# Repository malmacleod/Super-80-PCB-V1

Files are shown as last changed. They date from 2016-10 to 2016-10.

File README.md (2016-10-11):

# Super-80 PCB (V1)

This repository stores the KiCad files (schematic and PCB) for the work-in-progress task of creating a reproduction of the Super 80 Computer.

The schematic is fully drawn.

As at 11-OCT-2016, the PCB is about 50% completed.

This will be as close a copy as possible to the original design.  Once this board has been completed, a slightly modified version will then be created, to overcome problems associated with components that are no longer available (such as the keyswitches).

STATUS:

11-OCT-2016: Added bottom layer traces in the vicinity of the 3 24-pin ICs U26, U33 and U42.

10-OCT-2016: Initial upload of KiCad files to Github.

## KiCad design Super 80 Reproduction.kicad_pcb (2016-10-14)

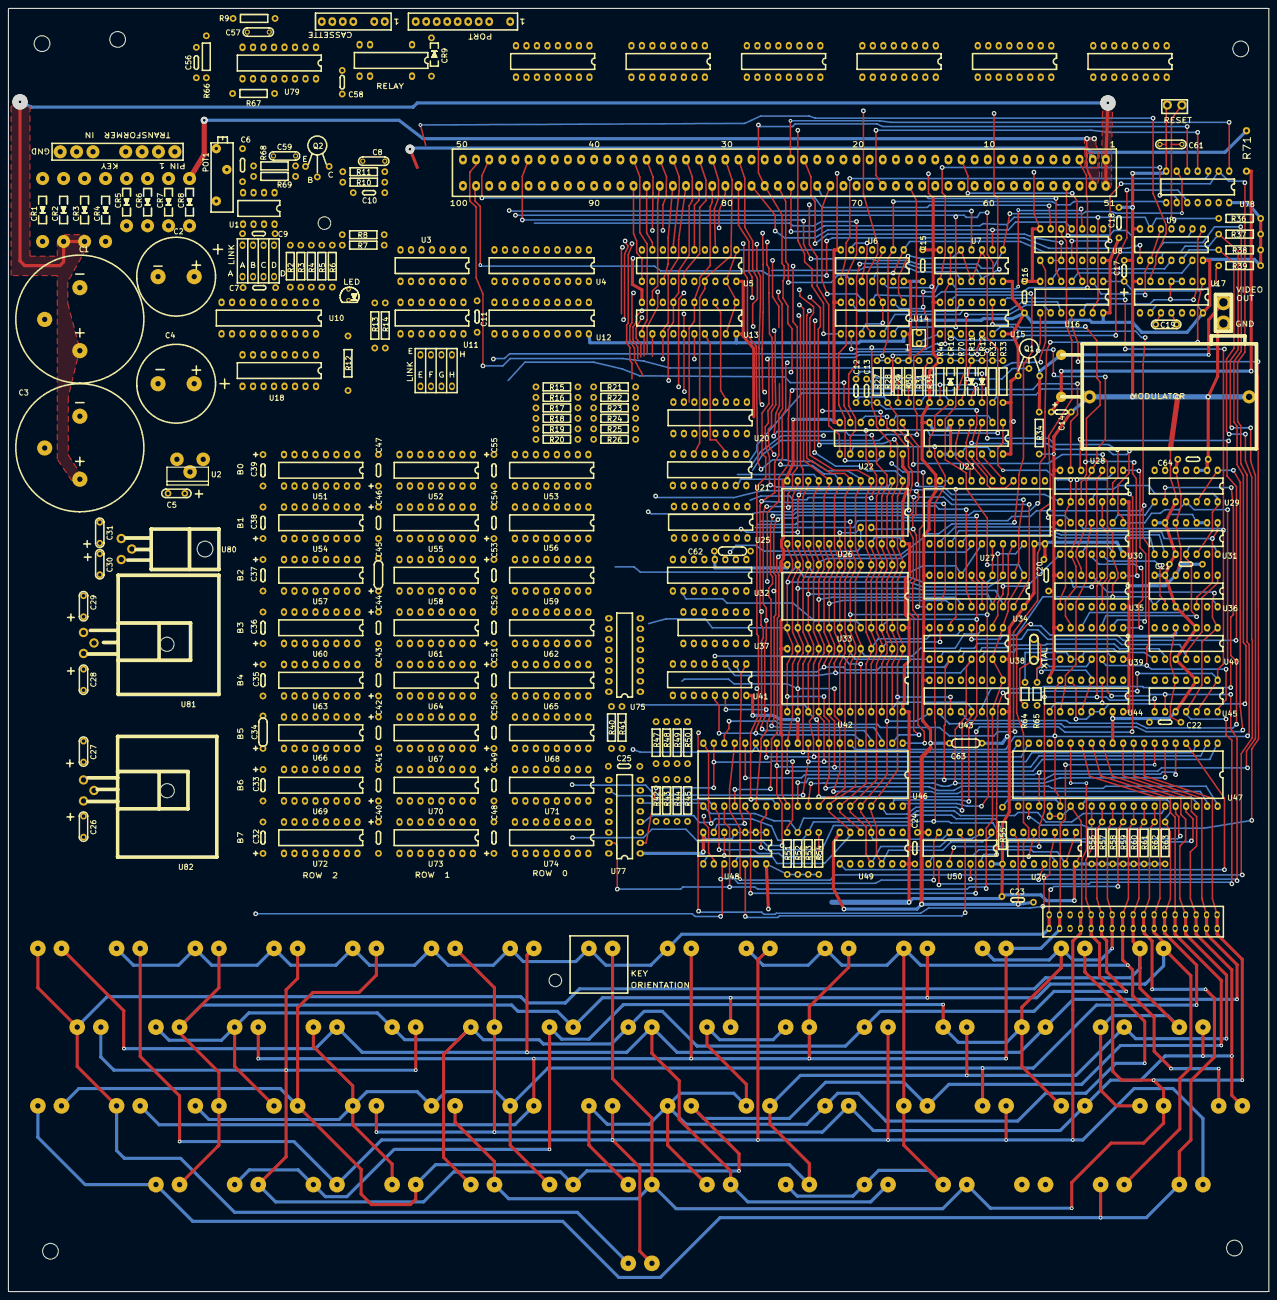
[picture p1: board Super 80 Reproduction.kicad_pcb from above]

Board: 2 copper layers, 305.0 x 310.5 mm, 312 parts (0 on the bottom side), 281 nets.

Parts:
C1, C3: 5600uF; S80-C1220-POL-600
C2: 1000uF; S80-C2-750-345
C4: 1000uF; S80-C4-750-345
C5: 10uF; S80-C160-POL-32
C6, C21: 0.1uF; S80-C315-32
C7, C9, C63: 0.1uF; S80-C310-32
C8, C57, C59: 0.01uF; S80-C210-32
C10, C11, C15, C16, C22, C25: 0.1uF; S80-C300-32
C12: 68pF; S80-C225-32
C13: 0.01uF; S80-C225-32
C14: 25uF 25V; S80-C190-POL-32
C17: 33uF TANT; S80-C17-200-32
C18, C56, C64: 0.1uF; S80-C290-32
C19: 0.1uF; S80-C200-32-2
C20: 0.1uF; S80-C20-300-32
C23: 0.1uF; S80-C23-300-32
C24: 0.1uF; S80-C24-300-32
C26, C27, C28, C29, C30, C31: 10uF; S80-C200-32-2
C32, C36, C43, C47, C48, C52: 0.1uF; S80-C300-POL-32-A1
C33, C37, C42, C46, C49, C53: 1.5uF TANT; S80-C300-POL-32-B1
C34, C45: 15uF TANT; S80-C310-POL-32-A1
C35, C39, C40, C44, C51, C55: 0.1uF; S80-C300-POL-32-B1
C38, C41, C50, C54: 15uF TANT; S80-C300-POL-32-A1
C58: 0.1uF; S80-C255-32
C61: 0.1uF; S80-C210-32
C62: 0.1uF; S80-C345-32
CR1, CR2, CR3, CR4: MUR420G; S80-D600-50
CR5, CR6, CR7, CR8: 1N4001; S80-D450-50
CR9: 1N914; S80-D365-32
CR10, CR11, CR12: 1N914; S80-D400-32
J1: 8 PIN HEADER; S80-J1-TRANSFORMER
J2: 7 PIN HEADER; S80-J2-CASSETTE
J3: 10 PIN HEADER; S80-J3-PORT
J4: 2 PIN HEADER; S80-J4-VIDEO
J5: S-100 CONNECTOR; S80-S100-CONNECTOR
J6: KEYBOARD CONNECTOR; S80-J6-KEYBRD
JP1: S80-LINK
JP2: JUMPER; S80-JP2
JP3: PRE-LINK; S80-LINK
KEY1, KEY2, KEY3, KEY4, KEY5, KEY6, KEY7, KEY9, KEY10, KEY11, KEY12, KEY13, KEY14, KEY15, KEY16, KEY17, KEY18, KEY19, KEY20, KEY21, KEY22, KEY23, KEY24, KEY25, KEY26, KEY27, KEY28, KEY29, KEY30, KEY32, KEY33, KEY34, KEY35, KEY36, KEY37, KEY38, KEY39, KEY40, KEY41, KEY42, KEY43, KEY44, KEY45, KEY46, KEY48, KEY49, KEY50, KEY51, KEY52, KEY53, KEY54, KEY55, KEY56, KEY57, KEY60, KEY100: S80-KEYSW-A; S80-KEYSW
KEY8: S80-KEYSW-A; S80-KEYSW-OUTLINE
KEY31, KEY47, KEY58, KEY59: S80-KEYSW-B; S80-KEYSW
LED1: 5MM RED LED; S80-LED1
MOD1: UM1082AUS; S80-RF-MOD-ORIG
POT1: 20K; S80-POT1
Q1: BC548; S80-Q1
Q2: BC327; S80-Q2
R2, R3, R4, R5, R6, R36, R39, R56, R57, R58, R59, R60, R61, R62, R63: 4.7K; S80-R400-32
R7: 100K; S80-R400-32
R8: 150R; S80-R400-32
R9: 270K; S80-R400-32
R10, R33, R51, R52, R53, R54: 10K; S80-R400-32
R11: 100R; S80-R400-32
R12: 180R; S80-R520-32
R13: 330; S80-R430-32
R14: 33; S80-R430-32
R15, R16, R17, R18, R19, R20, R41, R42, R43, R44, R45: 33R; S80-R400-32
R21, R22, R23, R24, R25, R26, R31, R40, R47, R48, R49, R50: 330R; S80-R400-32
R27, R28: 2.2K; S80-R400-32
R29, R30: 33K; S80-R400-32
R32, R70: 3.3K; S80-R400-32
R34: 56R; S80-R400-32
R35, R46: 15K; S80-R400-32
R37, R38: 1K; S80-R400-32
R55: 330R; S80-R540-32
R64, R65: 1K; S80-R220-32
R66: 22K; S80-R400-32
R67: 27K; S80-R400-32
R68: 47K; S80-R400-32
R69: 68K; S80-R400-32
R71: 270R 1W ??; S80-R71-385-32
RELAY1: 14-PIN DIL 5V SPDT RELAY; S80-RELAY-DIP-14
Ref**: H*; S80-HOLE-150
Ref**#2, Ref**#3: H*; S80-HOLE-120
Ref**#4, Ref**#5, Ref**#6, Ref**#7: H*; S80-HOLE-150
SW1: 4-WAY DIP SWITCH; S80-SW1-ABCD
SW2: 4-WAY DIP SWITCH; S80-SW2-EFGH
SW3: PCB MOM SW 2-PIN; S80-SW-RESET
U1: LM311; S80-DIP-8-300
U2: 7905T; S80-U2-7905
U3, U7, U78: 74LS02; S80-DIP-14-300
U4, U5, U10, U12, U13: 81LS95; S80-DIP-20-300
U6, U76: 74LS74; S80-DIP-14-300
U8, U15, U22, U39: 74LS04; S80-DIP-14-300
U9: 74LS05; S80-DIP-14-300
U11, U35, U49: 74LS30; S80-DIP-14-300
U14, U28, U37: 74LS00; S80-DIP-14-300
U16: 74LS14; S80-DIP-14-300
U17: 74121; S80-DIP-14-300
U18: 74LS174; S80-DIP-16-300
U20, U21: 74157; S80-DIP-16-300
U23: 74LS165; S80-DIP-16-300
U25, U44, U75: 74109; S80-DIP-16-300
U26: 2516 or 2532; S80-DIP-24-600
U27: 2513; S80-DIP-24-600
U29, U40, U45: 74LS93; S80-DIP-14-300
U30: 74LS86; S80-DIP-14-300
U31: 74LS90; S80-DIP-14-300
U32: 74LS138; S80-DIP-16-300
U33, U42: 2532; S80-DIP-24-600
U34: 74LS374; S80-DIP-20-300
U36: 74LS92; S80-DIP-14-300
U38, U43, U77: 74LS367; S80-DIP-16-300
U41: 74LS139; S80-DIP-16-300
U46: Z80 CPU; S80-DIP-40-600
U47: Z80 PIO; S80-DIP-40-600
U48: 74LS27; S80-DIP-14-300
U50: 74LS20; S80-DIP-14-300
U51, U52, U53, U54, U55, U56, U57, U58, U59, U60, U61, U62, U63, U64, U65, U66, U67, U68, U69, U70, U71, U72, U73, U74: 4116; S80-DIP-16-300
U79: 4046; S80-DIP-16-300
U80: 7812T; S80-U80-7812
U81: 7805T; S80-U81-7805
U82: 7805T; S80-U82-7805
XTAL1: 12MHz; S80-XTAL

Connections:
6LATCH*: U22.5, U41.4
12MHz: U15.13, U25.12, U39.12, U45.14
12MHz*: U15.12, U25.4, U75.4, U75.12, U76.3
+8V: C1.1, C3.1, C27.1, C29.1, CR2.2, CR3.2, J5.1, J5.51, U81.VI, U82.VI
+16V: C2.1, C31.1, CR6.2, CR7.2, J3.3, J5.2, R71.1, U80.VI
-16V: C4.2, CR5.1, CR8.1, J3.1, J5.52, U2.VI
/CPU & ROM/A0: U13.2, U26.8, U33.8, U38.11, U41.2, U42.8, U46.30, U47.5
/CPU & ROM/A1: U13.16, U26.7, U33.7, U38.13, U41.3, U42.7, U46.31, U47.6
/CPU & ROM/A2: U13.4, U26.6, U33.6, U38.9, U42.6, U46.32
/CPU & ROM/A3: U5.2, U26.5, U33.5, U38.3, U42.5, U46.33, U48.11, U49.6
/CPU & ROM/A4: U5.18, U26.4, U33.4, U38.5, U42.4, U46.34, U49.5
/CPU & ROM/A5: U13.18, U26.3, U33.3, U38.7, U42.3, U46.35, U49.11, U50.2
/CPU & ROM/A6: U5.4, U26.2, U33.2, U42.2, U43.9, U46.36, U49.4, U50.5
/CPU & ROM/A7: U13.14, U26.1, U33.1, U42.1, U43.11, U46.37, U49.12, U50.1
/CPU & ROM/A8: U5.14, U26.23, U33.23, U42.23, U43.13, U46.38
/CPU & ROM/A9: U5.6, U26.22, U33.22, U34.6, U42.22, U46.39
/CPU & ROM/A10: U13.12, U26.19, U33.19, U34.5, U42.19, U46.40
/CPU & ROM/A11: JP1.2, U5.12, U34.2, U46.1
/CPU & ROM/A12: U13.6, U32.1, U34.19, U46.2
/CPU & ROM/A13: U13.8, U32.2, U34.16, U46.3
/CPU & ROM/A14: U5.8, U34.15, U37.2, U41.14, U46.4
/CPU & ROM/A15: U5.16, U34.12, U37.1, U41.13, U46.5
/CPU & ROM/D0: U4.11, U10.3, U12.12, U18.3, U26.9, U27.17, U33.9, U42.9, U46.14, U47.19, U51.2, U51.14, U52.2, U52.14, U53.2, U53.14
/CPU & ROM/D1: U4.9, U10.9, U12.8, U18.4, U26.10, U27.18, U33.10, U34.7, U42.10, U46.15, U47.20, U54.2, U54.14, U55.2, U55.14, U56.2, U56.14
/CPU & ROM/D2: U4.17, U10.13, U12.18, U18.6, U26.11, U27.19, U33.11, U34.4, U42.11, U46.12, U47.1, U57.2, U57.14, U58.2, U58.14, U59.2, U59.14
/CPU & ROM/D3: U4.15, U12.16, U18.11, U26.13, U27.20, U33.13, U34.3, U42.13, U46.8, U47.40, U60.2, U60.14, U61.2, U61.14, U62.2, U62.14
/CPU & ROM/D4: U4.3, U10.17, U12.2, U18.13, U26.14, U27.21, U33.14, U34.18, U42.14, U46.7, U47.39, U63.2, U63.14, U64.2, U64.14, U65.2, U65.14
/CPU & ROM/D5: U4.5, U10.5, U12.4, U18.14, U26.15, U27.22, U33.15, U34.17, U42.15, U46.9, U47.38, U66.2, U66.14, U67.2, U67.14, U68.2, U68.14
/CPU & ROM/D6: U4.7, U10.15, U12.6, U26.16, U33.16, U34.14, U42.16, U46.10, U47.3, U69.2, U69.14, U70.2, U70.14, U71.2, U71.14
/CPU & ROM/D7: U4.13, U10.7, U12.14, U26.17, U33.17, U34.13, U42.17, U46.13, U47.2, U72.2, U72.14, U73.2, U73.14, U74.2, U74.14
/CPU & ROM/IOREQ*: R53.1, U46.20, U47.36, U77.4
/CPU & ROM/MEMREQ*: R51.1, U46.19, U77.2
/CPU & ROM/PA0: J6.7, J6.8, KEY2.2, KEY10.2, KEY26.2, KEY38.2, KEY43.2, KEY49.2, KEY59.2, KEY60.2, U47.15
/CPU & ROM/PA1: J6.21, J6.22, KEY3.2, KEY12.2, KEY15.2, KEY17.2, KEY22.2, KEY24.2, KEY33.2, KEY47.2, KEY58.2, U47.14
/CPU & ROM/PA2: J6.25, J6.26, KEY4.2, KEY16.2, KEY20.2, KEY39.2, KEY42.2, KEY48.2, KEY52.2, U47.13
/CPU & ROM/PA3: J6.27, J6.28, KEY5.2, KEY27.2, KEY29.2, KEY31.2, KEY34.2, KEY40.2, KEY50.2, KEY55.2, U47.12
/CPU & ROM/PA4: J6.29, J6.30, KEY6.2, KEY21.2, KEY30.2, KEY35.2, KEY41.2, KEY44.2, KEY46.2, U47.10
/CPU & ROM/PA5: J6.31, J6.32, KEY1.2, KEY7.2, KEY19.2, KEY23.2, KEY28.2, KEY54.2, KEY56.2, U47.9
/CPU & ROM/PA6: J6.33, J6.34, KEY8.2, KEY14.2, KEY36.2, KEY45.2, KEY51.2, KEY53.2, KEY57.2, U47.8
/CPU & ROM/PA7: J6.3, J6.4, KEY9.2, KEY11.2, KEY13.2, KEY18.2, KEY25.2, KEY32.2, KEY37.2, U47.7
/CPU & ROM/PB0: J6.23, J6.24, KEY19.1, KEY33.1, KEY35.1, KEY36.1, KEY37.1, KEY43.1, KEY50.1, KEY52.1, R63.1, U47.27
/CPU & ROM/PB1: J6.9, J6.10, KEY24.1, KEY25.1, KEY38.1, KEY39.1, KEY40.1, KEY41.1, KEY53.1, KEY54.1, R56.1, U47.28
/CPU & ROM/PB2: J6.11, J6.12, KEY17.1, KEY18.1, KEY20.1, KEY21.1, KEY23.1, KEY26.1, KEY34.1, KEY51.1, R57.1, U47.29
/CPU & ROM/PB3: J6.13, J6.14, KEY13.1, KEY14.1, KEY22.1, KEY27.1, KEY28.1, KEY44.1, KEY48.1, KEY49.1, R58.1, U47.30
/CPU & ROM/PB4: J6.1, J6.2, KEY2.1, KEY3.1, KEY4.1, KEY5.1, KEY6.1, KEY7.1, KEY8.1, KEY9.1, R59.1, U47.31
/CPU & ROM/PB5: J6.15, J6.16, KEY10.1, KEY11.1, KEY12.1, KEY42.1, KEY46.1, KEY55.1, KEY56.1, KEY57.1, R60.1, U47.32
/CPU & ROM/PB6: J6.17, J6.18, KEY1.1, KEY15.1, KEY16.1, KEY29.1, KEY30.1, KEY32.1, KEY45.1, KEY60.1, R61.1, U47.33
/CPU & ROM/PB7: J6.19, J6.20, KEY31.1, KEY47.1, KEY58.1, KEY59.1, R62.1, U47.34
/CPU & ROM/RD*: R52.1, U46.21, U47.35, U77.6, U77.11
/CPU & ROM/WR*: R54.1, U46.22, U77.10
/I/O/32K*: R3.1, SW1.6, U10.16
/I/O/48K*: R2.1, SW1.5, U10.6
/I/O/JP BASIC*: R4.1, SW1.7, U10.4
/I/O/PORT-5: J3.5, U18.12
/I/O/PORT-6: J3.6, U18.10
/I/O/PORT-7: J3.7, U10.8
/I/O/PORT-8: J3.8, U10.14
/I/O/TEST*: R5.1, SW1.8, U10.18
/RAM/AA0: R16.2, R22.1, U20.4
/RAM/AA1: R15.2, R21.1, U20.7
/RAM/AA2: R18.2, R24.1, U20.9
/RAM/AA3: R17.2, R23.1, U20.12
/RAM/AA4: R20.2, R26.1, U21.7
/RAM/AA5: R19.2, R25.1, U21.4
/RAM/AA6: R40.1, R41.1, U21.9
/RAM/BAA0: R16.1, U51.5, U52.5, U53.5, U54.5, U55.5, U56.5, U57.5, U58.5, U59.5, U60.5, U61.5, U62.5, U63.5, U64.5, U65.5, U66.5, U67.5, U68.5, U69.5, U70.5, U71.5, U72.5, U73.5, U74.5
/RAM/BAA1: R15.1, U51.12, U52.12, U53.12, U54.12, U55.12, U56.12, U57.12, U58.12, U59.12, U60.12, U61.12, U62.12, U63.12, U64.12, U65.12, U66.12, U67.12, U68.12, U69.12, U70.12, U71.12, U72.12, U73.12, U74.12
/RAM/BAA2: R18.1, U51.6, U52.6, U53.6, U54.6, U55.6, U56.6, U57.6, U58.6, U59.6, U60.6, U61.6, U62.6, U63.6, U64.6, U65.6, U66.6, U67.6, U68.6, U69.6, U70.6, U71.6, U72.6, U73.6, U74.6
/RAM/BAA3: R17.1, U51.11, U52.11, U53.11, U54.11, U55.11, U56.11, U57.11, U58.11, U59.11, U60.11, U61.11, U62.11, U63.11, U64.11, U65.11, U66.11, U67.11, U68.11, U69.11, U70.11, U71.11, U72.11, U73.11, U74.11
/RAM/BAA4: R20.1, U51.7, U52.7, U53.7, U54.7, U55.7, U56.7, U57.7, U58.7, U59.7, U60.7, U61.7, U62.7, U63.7, U64.7, U65.7, U66.7, U67.7, U68.7, U69.7, U70.7, U71.7, U72.7, U73.7, U74.7
/RAM/BAA5: R19.1, U51.10, U52.10, U53.10, U54.10, U55.10, U56.10, U57.10, U58.10, U59.10, U60.10, U61.10, U62.10, U63.10, U64.10, U65.10, U66.10, U67.10, U68.10, U69.10, U70.10, U71.10, U72.10, U73.10, U74.10
/RAM/BAA6: R41.2, U51.13, U52.13, U53.13, U54.13, U55.13, U56.13, U57.13, U58.13, U59.13, U60.13, U61.13, U62.13, U63.13, U64.13, U65.13, U66.13, U67.13, U68.13, U69.13, U70.13, U71.13, U72.13, U73.13, U74.13
/RAM/CAS0*: R45.2, U53.15, U56.15, U59.15, U62.15, U65.15, U68.15, U71.15, U74.15
/RAM/CAS1*: R44.2, U52.15, U55.15, U58.15, U61.15, U64.15, U67.15, U70.15, U73.15
/RAM/CAS2*: R43.2, U51.15, U54.15, U57.15, U60.15, U63.15, U66.15, U69.15, U72.15
/RAM/RAS*: R42.2, U51.4, U52.4, U53.4, U54.4, U55.4, U56.4, U57.4, U58.4, U59.4, U60.4, U61.4, U62.4, U63.4, U64.4, U65.4, U66.4, U67.4, U68.4, U69.4, U70.4, U71.4, U72.4, U73.4, U74.4
/RAM/S100-A0: J5.79, U13.3, U20.3
/RAM/S100-A1: J5.80, U13.15, U20.6
/RAM/S100-A2: J5.81, U13.5, U20.10
/RAM/S100-A3: J5.31, U5.3, U20.13
/RAM/S100-A4: J5.30, U5.17, U21.6
/RAM/S100-A5: J5.29, U13.17, U21.3
/RAM/S100-A6: J5.82, U5.5, U21.10
/RAM/S100-A7: J5.83, U13.13, U20.2
/RAM/S100-A8: J5.84, U5.13, U20.5
/RAM/S100-A9: J5.34, U5.7, U20.11
/RAM/S100-A10: J5.37, U13.11, U20.14
/RAM/S100-A11: J5.87, U5.11, U21.5
/RAM/S100-A12: J5.33, U13.7, U21.2
/RAM/S100-A13: J5.85, U13.9, U21.11
/S-100 Interface/S100-A14: J5.86, U5.9
/S-100 Interface/S100-A15: J5.32, U5.15
/S-100 Interface/S100-CLK-B*: J5.24, U8.9, U8.10
/S-100 Interface/S100-CLOCK-B*: J5.49, U8.8
/S-100 Interface/S100-DI0: J5.95, U4.12
/S-100 Interface/S100-DI1: J5.94, U4.8
/S-100 Interface/S100-DI2: J5.41, U4.18
/S-100 Interface/S100-DI3: J5.42, U4.16
/S-100 Interface/S100-DI4: J5.91, U4.2
/S-100 Interface/S100-DI5: J5.92, U4.4
/S-100 Interface/S100-DI6: J5.93, U4.6
/S-100 Interface/S100-DI7: J5.43, U4.14
/S-100 Interface/S100-DIN*: U4.19, U11.8
/S-100 Interface/S100-DO0: J5.36, U12.11
/S-100 Interface/S100-DO1: J5.35, U12.9
/S-100 Interface/S100-DO2: J5.88, U12.17
/S-100 Interface/S100-DO3: J5.89, U12.15
/S-100 Interface/S100-DO4: J5.38, U12.3
/S-100 Interface/S100-DO5: J5.39, U12.5
/S-100 Interface/S100-DO6: J5.40, U12.7
/S-100 Interface/S100-DO7: J5.90, U12.13
/S-100 Interface/S100-INT*: J5.73, U16.5
/S-100 Interface/S100-NMI*: J5.12, U16.3
/S-100 Interface/S100-POC*: J5.99, U9.8
/S-100 Interface/S100-PRFSH*: J5.66, JP2.1
/S-100 Interface/S100-PSTVAL: J5.25, U78.1
/S-100 Interface/S100-PSYNC: J5.76, U6.9
/S-100 Interface/S100-RDY*: J5.72, U14.5
/S-100 Interface/S100-RESET*: C61.2, J5.75, R36.1, SW3.2, U9.6, U16.13
/S-100 Interface/S100-SINTA: J5.96, U7.13, U14.13
/S-100 Interface/S100-SLAVE-CLR*: J5.54, U9.2
/S-100 Interface/S100-SOUT: J5.45, U7.1, U78.6
/S-100 Interface/S100-XRDY*: J5.3, U14.4
AS/W*: SW2.1, U11.4, U25.6
BUSAK*: U16.9, U34.1, U38.1, U38.15, U43.1, U43.15, U46.23, U77.15
BUSREQ*: U28.11, U46.25
C000-FFFF*: U3.5, U25.5, U37.3, U37.4
CLK: R55.1, U8.11, U44.7, U46.6, U47.25, U78.2
CLK2: U6.1, U6.11, U44.6, U44.13, U44.14
DECODEF*: U48.10, U50.6
GND: C1.2, C2.2, C3.2, C4.1, C5.1, C6.2, C7.1, C8.1, C9.1, C11.1, C14.2, C15.1, C16.1, C17.2, C18.1, C20.2, C21.1, C22.1, C23.2, C24.1, C25.2, C26.2, C27.2, C28.2, C29.2, C30.2, C31.2, C32.1, C33.2, C34.1, C35.2, C36.1, C37.2, C38.1, C39.2, C40.2, C41.1, C42.2, C43.1, C44.2, C45.1, C46.2, C47.1, C48.1, C49.2, C50.1, C51.2, C52.1, C53.2, C54.1, C55.2, C58.2, C59.2, C61.1, C62.1, C63.1, C64.2, CR1.1, CR4.1, CR9.1, J1.2, J1.3, J1.8, J2.3, J2.5, J3.4, J4.2, J5.26, J5.50, J5.100, MOD1.3, MOD1.4, POT1.B, R9.1, R11.1, R32.2, R34.2, R35.2, R46.1, R67.1, RELAY1.9, SW1.1, SW1.2, SW1.3, SW1.4, SW3.1, U1.1, U1.4, U2.GND, U3.7, U4.10, U5.1, U5.10, U5.19, U6.7, U6.12, U7.7, U8.7, U9.7, U10.10, U11.7, U12.1, U12.10, U12.19, U13.1, U13.10, U13.19, U14.7, U15.7, U16.7, U17.7, U18.8, U20.8, U20.15, U21.8, U21.15, U22.7, U23.6, U23.8, U23.10, U23.11, U23.12, U23.15, U25.8, U26.12, U27.10, U27.11, U28.7, U29.2, U29.3, U29.10, U30.7, U31.2, U31.3, U31.6, U31.7, U31.10, U32.4, U32.8, U33.12, U34.10, U35.7, U36.6, U36.7, U36.10, U37.7, U38.8, U39.7, U40.2, U40.3, U40.10, U41.8, U42.12, U43.8, U44.8, U44.15, U45.2, U45.3, U45.10, U46.29, U47.11, U48.1, U48.2, U48.3, U48.4, U48.7, U49.7, U50.7, U51.16, U52.16, U53.16, U54.16, U55.16, U56.16, U57.16, U58.16, U59.16, U60.16, U61.16, U62.16, U63.16, U64.16, U65.16, U66.16, U67.16, U68.16, U69.16, U70.16, U71.16, U72.16, U73.16, U74.16, U75.8, U76.7, U77.1, U77.8, U77.12, U78.7, U79.5, U79.8, U80.GND, U81.GND, U82.GND
HALT*: U8.5, U46.18
IEO: U16.11, U47.22
INPORT*: U10.1, U10.19, U41.6
INT*: R37.1, U9.10, U46.16, U47.23
IOREQ-BUFRD*: U7.3, U7.5, U7.11, U14.1, U48.9, U48.13, U77.5
M1*: U3.6, U7.12, U22.9, U46.27, U47.37
MEM: U25.13, U25.14, U32.3, U37.11
MEMREQ-BUFRD*: U7.8, U14.2, U37.12, U77.3, U78.9
MREQ2*: U28.6, U37.13
MRESET: U3.9, U17.6
MRESET*: U17.1, U46.26
unnamed: R43.1, R48.2, U41.10
unnamed: U41.15, U75.7
unnamed: U75.2, U75.3, U75.10
unnamed: R45.1, R50.2, U41.12
unnamed: R44.1, R49.2, U41.11
unnamed: U25.7, U75.13, U75.14
unnamed: U20.1, U21.1, U75.9
unnamed: R42.1, R47.2, U25.2, U25.3, U25.9
unnamed: R8.1, U18.5
unnamed: C10.1, J2.4
unnamed: CR9.2, Q2.C, RELAY1.6
unnamed: R12.2, U18.15
unnamed: Q2.B, R8.2
unnamed: J2.1, RELAY1.13
unnamed: J2.2, RELAY1.7
unnamed: C10.2, R10.2, R11.2
unnamed: R7.1, U18.2
unnamed: C8.2, R7.2, R10.1
unnamed: LED1.2, R12.1
unnamed: C57.2, U79.6
unnamed: C57.1, U79.7
unnamed: R67.2, U79.11
unnamed: R9.2, U79.12
unnamed: U79.3, U79.4
unnamed: R69.2, U79.2
unnamed: C59.1, R68.2, U1.2
unnamed: J2.6, R66.1
unnamed: C56.2, R66.2
unnamed: R68.1, R69.1, U79.9
unnamed: C56.1, U79.14
unnamed: C6.1, POT1.W, U1.3
unnamed: R6.1, U1.7, U10.2
unnamed: U48.5, U48.8
unnamed: U41.1, U48.6
unnamed: U18.9, U22.6
unnamed: U11.11, U14.11
unnamed: SW2.5, U11.1
unnamed: SW2.6, U11.2
unnamed: SW2.7, U11.3
unnamed: SW2.8, U11.12
unnamed: U14.12, U16.10
unnamed: C19.2, U17.11
unnamed: C19.1, U17.10
unnamed: U9.1, U16.12, U17.3, U17.4
unnamed: C17.1, R39.1, U16.1
unnamed: J5.68, U78.4
unnamed: J5.44, U22.8
unnamed: U9.5, U9.9, U16.2
unnamed: U9.11, U16.6
unnamed: U9.13, U16.4
unnamed: JP2.2, U15.8
unnamed: U6.6, U6.10
unnamed: U15.9, U78.10
unnamed: U14.6, U15.5
unnamed: J5.47, U7.10
unnamed: J5.46, U7.4
unnamed: J5.97, U14.8
unnamed: U6.3, U14.3, U14.10
unnamed: J5.48, U8.6
unnamed: U6.8, U78.3
unnamed: J5.78, U7.2, U8.4
unnamed: U23.13, U27.4
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

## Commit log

2016-10-10 Add files via upload
    Snapshot of work-in-progress version as at Mon 10.10.2016
    [CPU.sch, RAM.sch, Super 80 Reproduction.kicad_pcb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]
2016-10-11 Add files via upload
    Added bottom layer traces in the vicinity of the 3 24-pin ICs U26, U33 and U42.
    [Super 80 Reproduction.kicad_pcb]
2016-10-11 Add files via upload
    Reflects additional PCB traces added on 11.10.2016 (mostly bottom layer in the vicinity of the ICs U6 to U22).
    [Super 80 Reproduction.kicad_pcb]
2016-10-14 Add files via upload
    Added top layer tracks in the vicinity of U5 and U13.
    [Super 80 Reproduction.kicad_pcb]
